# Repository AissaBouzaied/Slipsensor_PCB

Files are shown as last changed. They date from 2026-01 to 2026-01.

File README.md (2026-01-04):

# Slipsensor_PCB
Small and simple PCB that gives 5V and 12V power to our slipsensor which measures the speed of the car and yaw rate. These measurments go through some signal processing in the pcb then to the ECU. This PCB was done as prototype solution to test our slipsensor and the signal processing(analog and digital). 

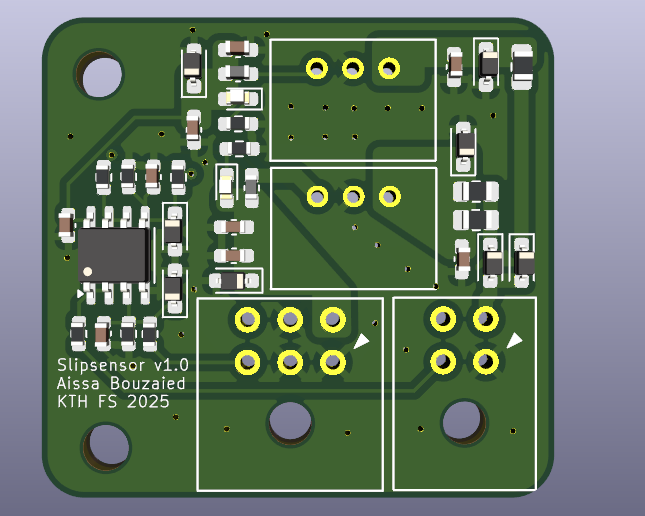
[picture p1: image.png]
imagealt


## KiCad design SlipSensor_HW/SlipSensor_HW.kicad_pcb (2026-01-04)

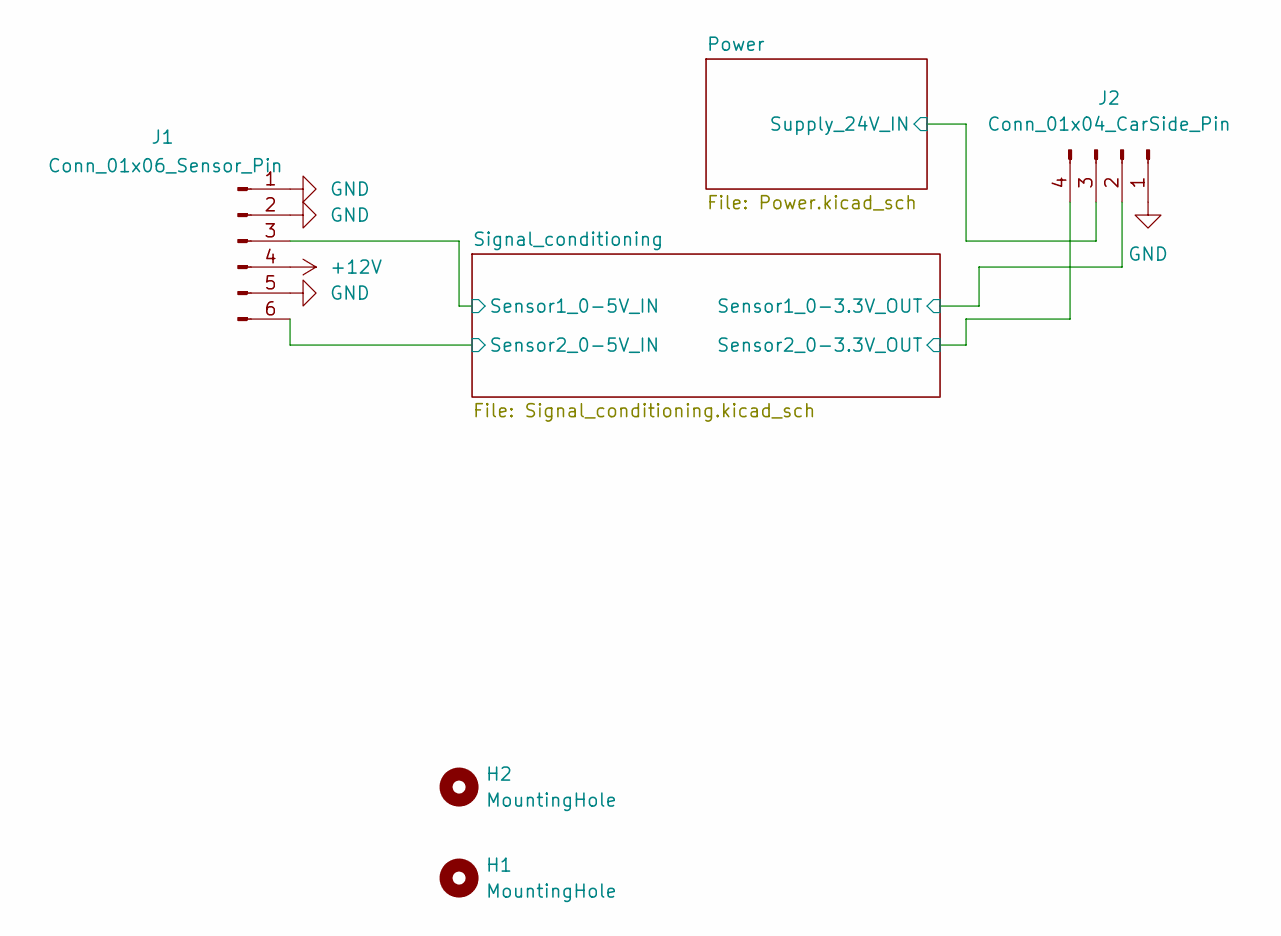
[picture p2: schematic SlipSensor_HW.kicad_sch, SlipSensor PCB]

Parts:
H1, H2: MountingHole; MountingHole_3.2mm_M3
J1: Conn_01x06_Sensor_Pin; Wurth-MPC3_02x03_angle
J2: Conn_01x04_CarSide_Pin; Wurth-MPC3_02x02_angle

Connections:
+12V: J1.4; also elsewhere on the board
/Power/Supply_24V_IN: J2.3; also elsewhere on the board
/Signal_conditioning/Sensor1_0-3.3V_OUT: J2.2; also elsewhere on the board
/Signal_conditioning/Sensor1_0-5V_IN: J1.3; also elsewhere on the board
/Signal_conditioning/Sensor2_0-3.3V_OUT: J2.4; also elsewhere on the board
/Signal_conditioning/Sensor2_0-5V_IN: J1.6; also elsewhere on the board
GND: J1.1, J1.2, J1.5, J2.1; also elsewhere on the board

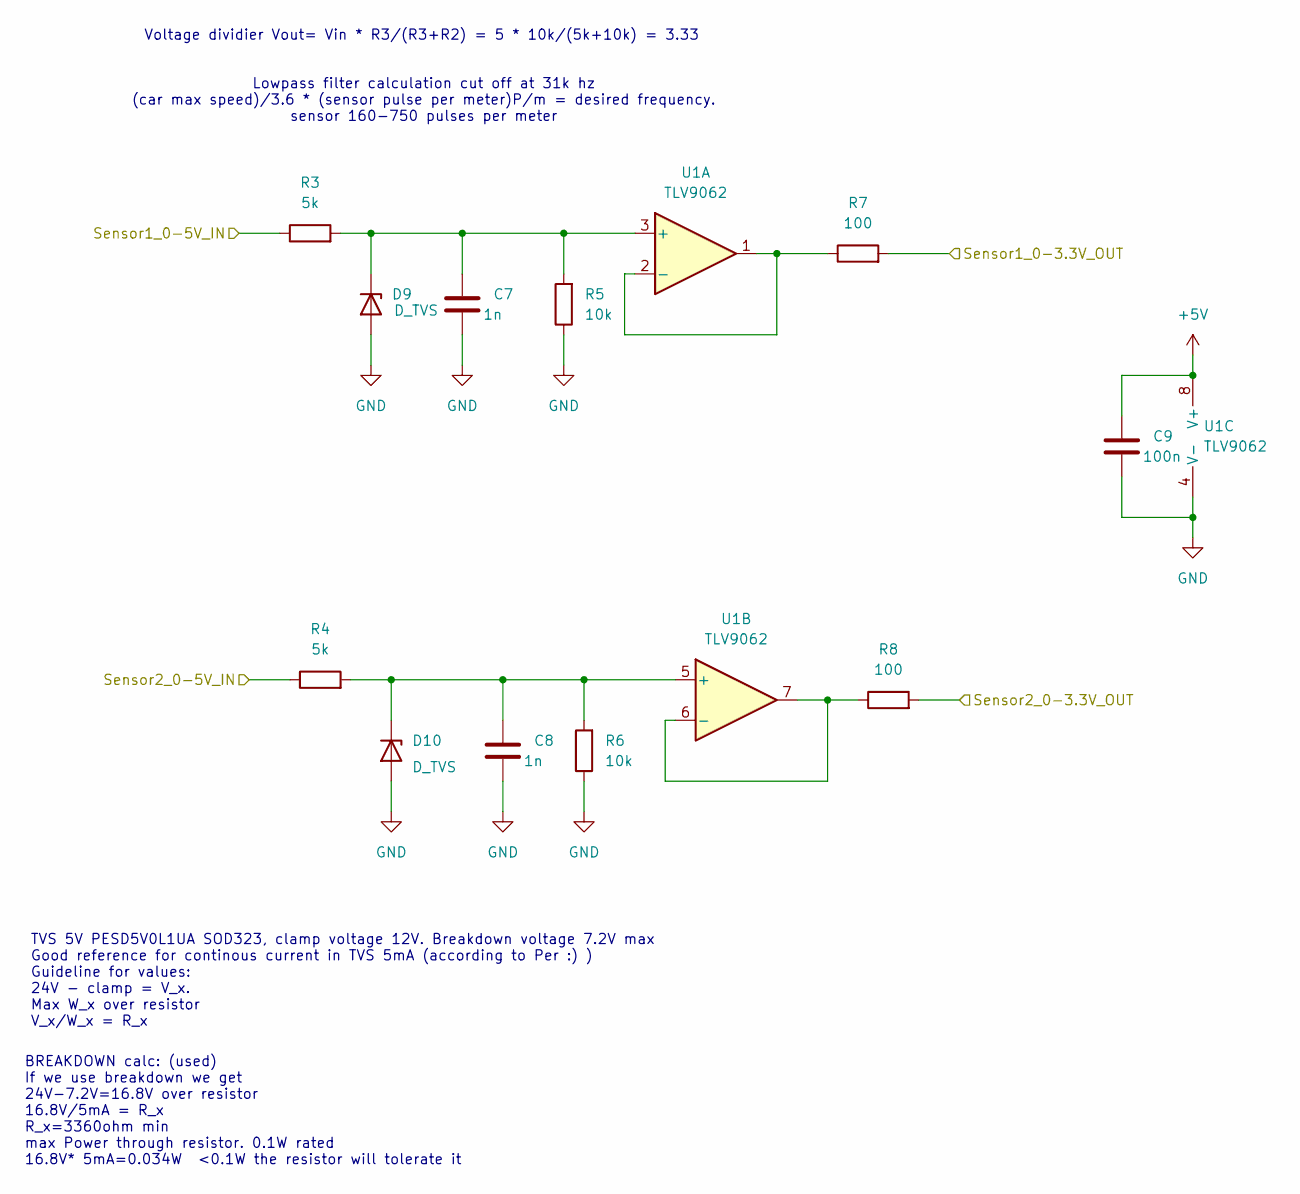
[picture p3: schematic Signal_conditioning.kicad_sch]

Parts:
C7, C8: 1n; C_0603_1608Metric
C9: 100n; C_0603_1608Metric
D9, D10: D_TVS; D_SOD-323_HandSoldering
R3, R4: 5k; R_0603_1608Metric
R5, R6: 10k; R_0603_1608Metric
R7, R8: 100; R_0603_1608Metric
U1: TLV9062; SOIC-8_3.9x4.9mm_P1.27mm

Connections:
+5V: C9.1, U1.8 (V+); also elsewhere on the board
/Signal_conditioning/Sensor1_0-3.3V_OUT: R7.2; also elsewhere on the board
/Signal_conditioning/Sensor1_0-5V_IN: R3.1; also elsewhere on the board
/Signal_conditioning/Sensor2_0-3.3V_OUT: R8.2; also elsewhere on the board
/Signal_conditioning/Sensor2_0-5V_IN: R4.1; also elsewhere on the board
GND: C7.2, C8.2, C9.2, D9.2 (A), D10.2 (A), R5.1, R6.1, U1.4 (V-); also elsewhere on the board
unnamed: C7.1, D9.1 (K), R3.2, R5.2, U1.3 (+)
unnamed: C8.1, D10.1 (K), R4.2, R6.2, U1.5 (+)
unnamed: R7.1, U1.1, U1.2 (-)
unnamed: R8.1, U1.6 (-), U1.7

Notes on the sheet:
TVS 5V PESD5V0L1UA SOD323, clamp voltage 12V. Breakdown voltage 7.2V max Good reference for continous current in TVS 5mA (according to Per :) ) Guideline for values: 24V - clamp = V_x. Max W_x over resistor V_x/W_x = R_x
Lowpass filter calculation cut off at 31k hz (car max speed)/3.6 * (sensor pulse per meter)P/m = desired frequency. sensor 160-750 pulses per meter
BREAKDOWN calc: (used) If we use breakdown we get 24V-7.2V=16.8V over resistor 16.8V/5mA = R_x R_x=3360ohm min max Power through resistor. 0.1W rated 16.8V* 5mA=0.034W <0.1W the resistor will tolerate it
Voltage dividier Vout= Vin * R3/(R3+R2) = 5 * 10k/(5k+10k) = 3.33

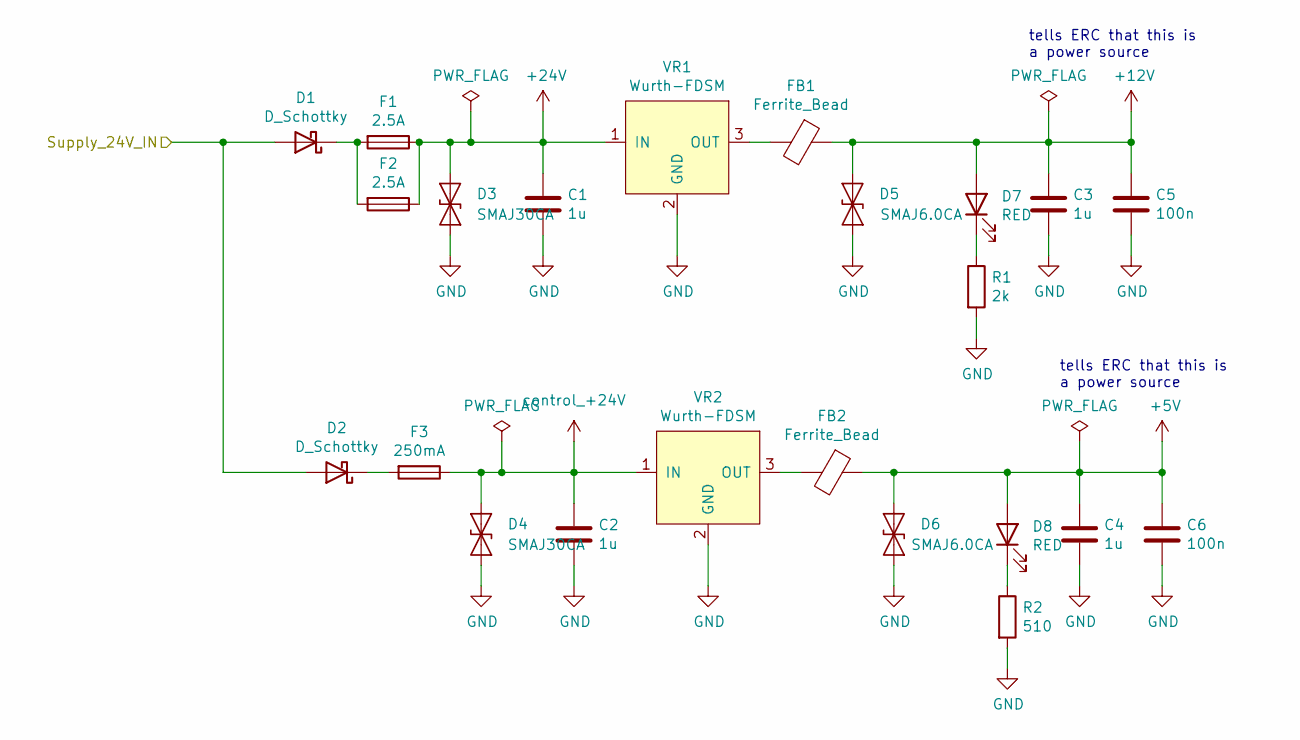
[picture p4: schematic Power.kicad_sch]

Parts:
C1, C2, C3, C4: 1u; C_0603_1608Metric_Pad1.08x0.95mm_HandSolder
C5, C6: 100n; C_0603_1608Metric_Pad1.08x0.95mm_HandSolder
D1, D2: D_Schottky; D_SOD-323_HandSoldering
D3, D4: SMAJ30CA; D_SOD-323_HandSoldering
D5, D6: SMAJ6.0CA; D_SOD-323_HandSoldering
D7, D8: RED; LED_0603_1608Metric_Pad1.05x0.95mm_HandSolder
F1, F2: 2.5A; Fuse_0805_2012Metric_Pad1.15x1.40mm_HandSolder
F3: 250mA; Fuse_0805_2012Metric_Pad1.15x1.40mm_HandSolder
FB1, FB2: Ferrite_Bead; L_0603_1608Metric_Pad1.05x0.95mm_HandSolder
R1: 2k; R_0603_1608Metric_Pad0.98x0.95mm_HandSolder
R2: 510; R_0603_1608Metric_Pad0.98x0.95mm_HandSolder
VR1, VR2: Wurth-FDSM

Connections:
+5V: C4.1, C6.1, D6.1 (A1), D8.2 (A), FB2.1; also elsewhere on the board
+12V: C3.1, C5.1, D5.1 (A1), D7.2 (A), FB1.1; also elsewhere on the board
+24V: C1.1, D3.1 (A1), F1.1, F2.1, VR1.1 (IN)
/Power/Supply_24V_IN: D1.2 (A), D2.2 (A); also elsewhere on the board
GND: C1.2, C2.2, C3.2, C4.2, C5.2, C6.2, D3.2 (A2), D4.2 (A2), D5.2 (A2), D6.2 (A2), R1.2, R2.2, VR1.2 (GND), VR2.2 (GND); also elsewhere on the board
unnamed: D1.1 (K), F1.2, F2.2
unnamed: D2.1 (K), F3.2
unnamed: D7.1 (K), R1.1
unnamed: D8.1 (K), R2.1
unnamed: FB1.2, VR1.3 (OUT)
unnamed: FB2.2, VR2.3 (OUT)
control_+24V: C2.1, D4.1 (A1), F3.1, VR2.1 (IN)

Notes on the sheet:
tells ERC that this is a power source

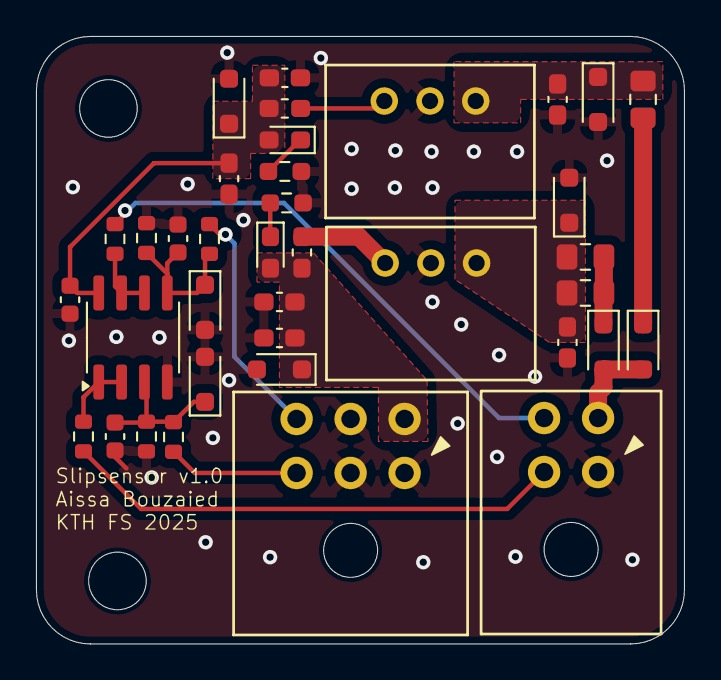
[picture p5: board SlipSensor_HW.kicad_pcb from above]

Board: 2 copper layers, 36.0 x 33.8 mm, 39 parts (0 on the bottom side), 20 nets.
